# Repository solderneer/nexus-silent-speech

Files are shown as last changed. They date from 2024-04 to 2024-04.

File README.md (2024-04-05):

# Nexus, a session-independent silent speech interface
A novel approach to session-independent silent speech recognition systems with a multiplexed star electrode array, developed for my final year dissertation at University College London (UCL). Includes datasets, code, and electronics CAD files.

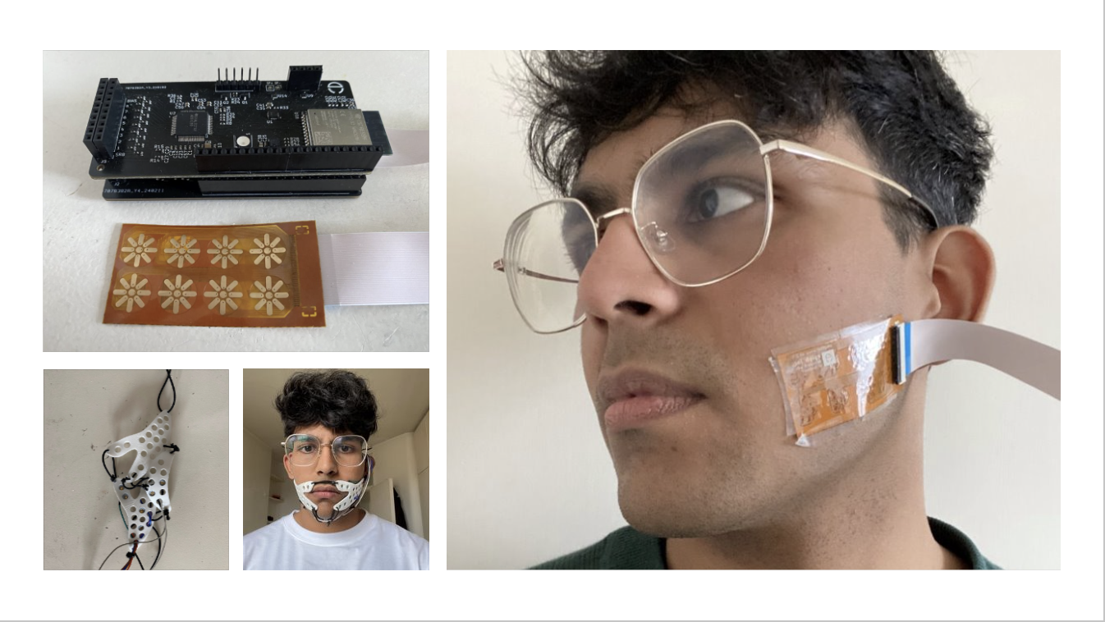
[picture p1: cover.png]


## Overview
This repository houses my final year dissertation project at University College London (UCL), focused on developing a novel multiplexed star electrode array to address the challenges of cross-session variability in silent speech recognition systems. This innovative approach leverages configurable electrode orientations to significantly enhance the signal-to-noise ratio (SNR) of surface electromyography (sEMG) signals, leading to improved recognition accuracy across sessions.

## Project Objectives
- To investigate the impact of cross-session variability on the accuracy of silent speech recognition systems.
- To design, develop, and evaluate a multiplexed star electrode array capable of adjusting electrode orientations for optimal muscle-electrode alignment.
- To compare the performance of the novel star electrode array against traditional electrode configurations in terms of SNR and silent speech recognition accuracy.

## Results Summary
The project successfully demonstrated the potential of the star electrode array to achieve superior muscle-electrode alignment, resulting in a significant increase in SNR compared to control configurations. Most notably, the array displayed a remarkable 41% relative improvement in cross-session classification accuracy, underscoring its effectiveness in mitigating the challenges posed by session-dependent variability.

## Contents
- `datasets/`: Contains the sEMG datasets collected during the project, across multiple sessions and with different electrode configurations.
- `code/`: Includes all code developed for signal acquisition, signal processing, feature extraction, and classification tasks.
- `cad/`: Houses the electronics CAD files for the star electrode array and control circuitry, enabling replication and further research.
- `docs/`: Additional project documentation, including project report and presentation slides.

## Contact
For any inquiries or collaboration proposals, please contact [Shan](https://solderneer.me) at [sudhar393@gmail.com](mailto://sudhar393@gmail.com).

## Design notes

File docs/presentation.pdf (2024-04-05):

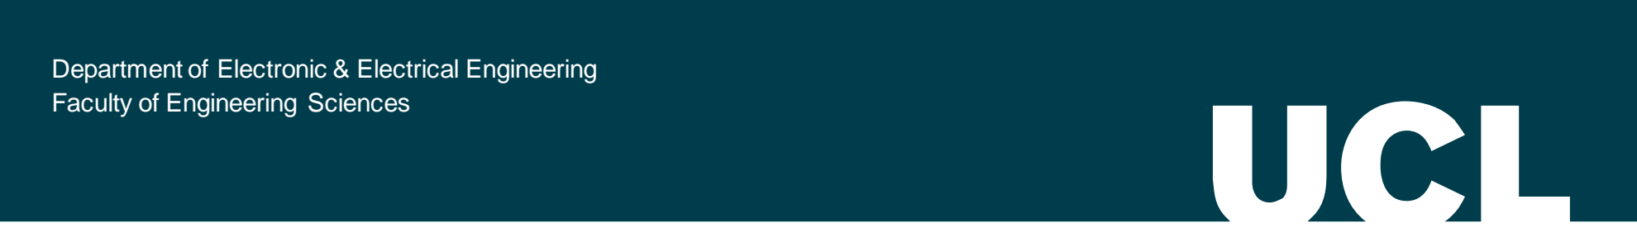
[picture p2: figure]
Faculty of Engineering Sciences

Slide 1 of 7

# A multiplexed star electrode array for session-independent silent speech recognition

# Sudharshan Sundaramahalingam

## Supervisor: Dr Arsam Shiraz

Department of Electronic & Electrical Engineering

### Silent speech recognition

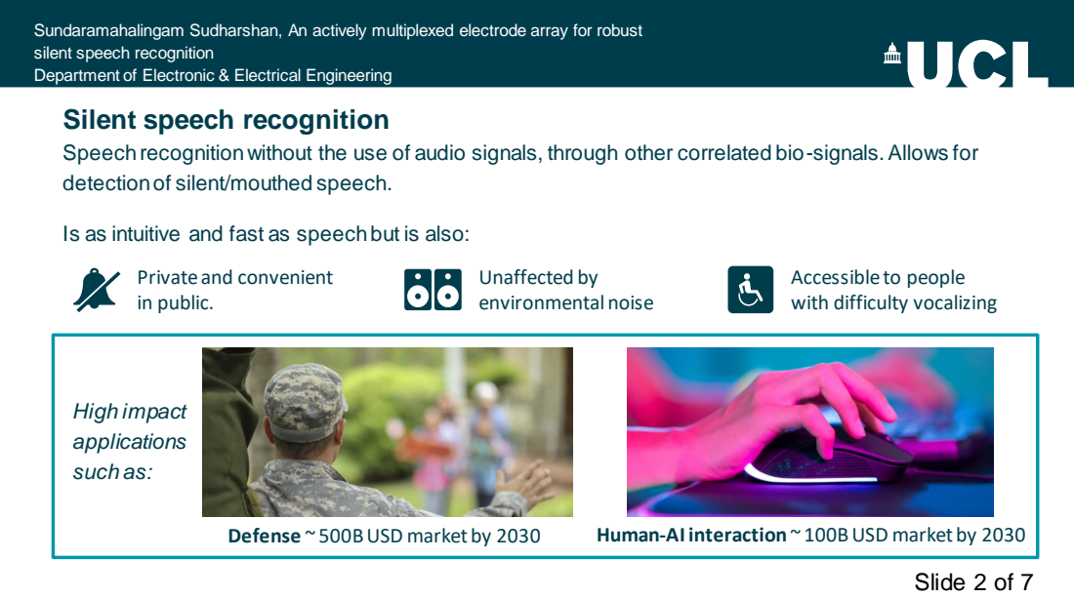
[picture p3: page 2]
Unaffected by environmental noise; High impact; applications; such as:; Defense ~ 500B USD market by 2030; Human-AI interaction ~ 100B USD market by 2030

Sundaramahalingam Sudharshan, An actively multiplexed electrode array for robust
silent speech recognition
Department of Electronic & Electrical Engineering

Speech recognition without the use of audio signals, through other correlated bio-signals. Allows for
detection of silent/mouthed speech.

Is as intuitive and fast as speech but is also:

Private and convenient
in public.

Accessible to people
with difficulty vocalizing

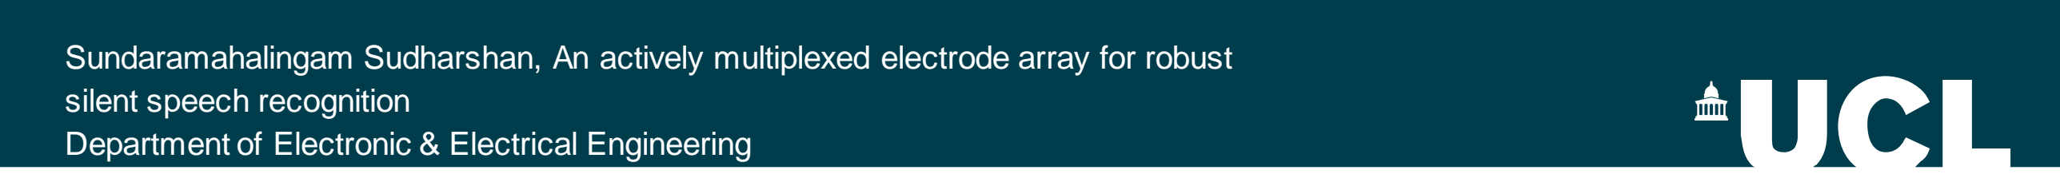
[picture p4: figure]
silent speech recognition

Department of Electronic & Electrical Engineering

### EMG-based silent speech recognition

Electromyography (EMG) signals from facial muscles is a common modality for silent speech recognition.

Electrodes | Signal Acquisition

Digital
Filters

Word
Classifier

Typical Architecture:

System performance requires precise electrode positions, accuracy reduces to 40% after electrode shift.

State of the art
AlterEgo (2019), 91% accuracy over a 30-word vocabulary

Replicated state-of-the-art with a custom electrode brace

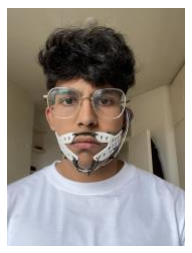
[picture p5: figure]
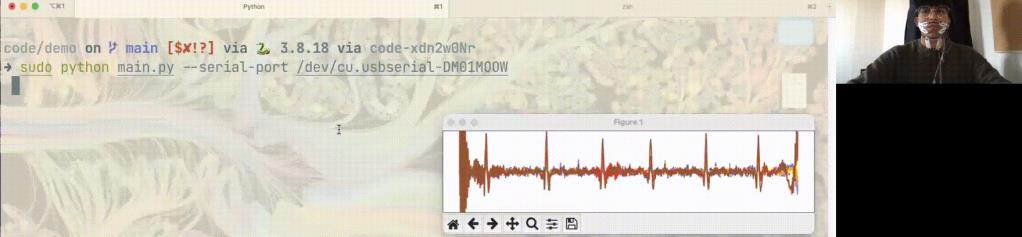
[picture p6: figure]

Research Question:
Investigating the impact of electrode alignment with facial muscles to maximise signal-to-noise ratio (SNR) in silent speech interfaces.

Department of Electronic & Electrical Engineering

### Design and Development

Develop an 8-channel electrode array capable of actively switching the orientation of its electrodes.

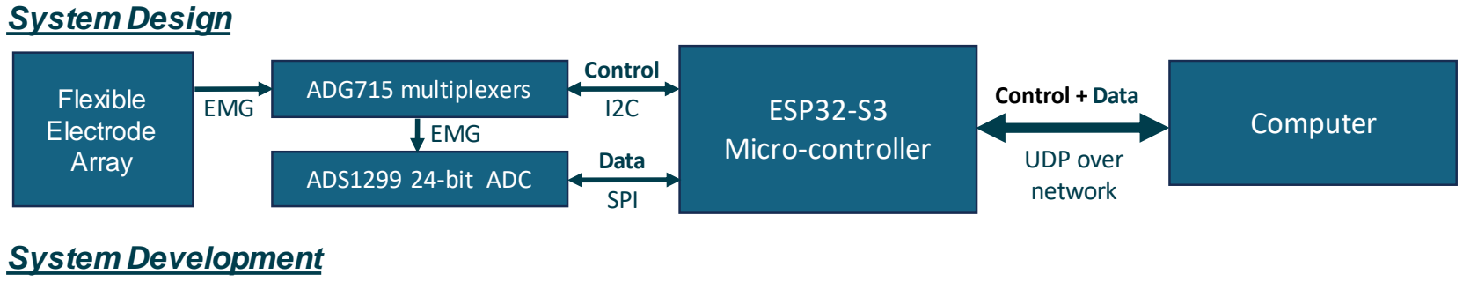
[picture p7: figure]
System Design; Flexible Electrode Array; ADG715 multiplexers; ADS1299 24-bit ADC; ESP32-S3 Micro-controller; Computer EMG EMG; Control I2C; Data SPI; Control + Data; UDP over network; System Development
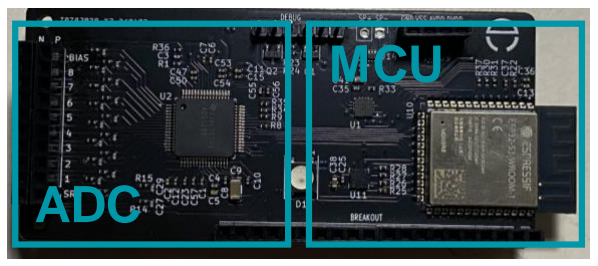
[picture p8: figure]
ADC; MCU
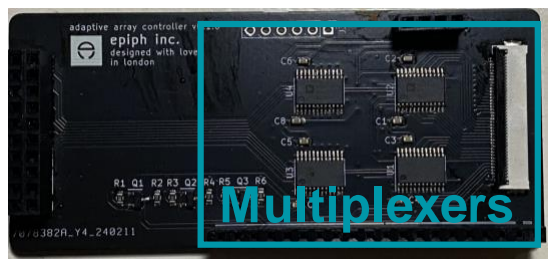
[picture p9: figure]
Multiplexers
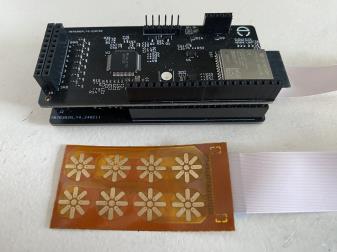
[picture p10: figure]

Main Control Board | Multiplexer Board | Flexible Electrodes (top) multiplexed, (bottom) control

Full Setup

Department of Electronic & Electrical Engineering

### Experimental Procedure and Development

Methodology

1. Record one minute of noise in a relaxed state.
2. Record a phonetically balanced passage that ensures a variety of speech muscle activations are sampled.

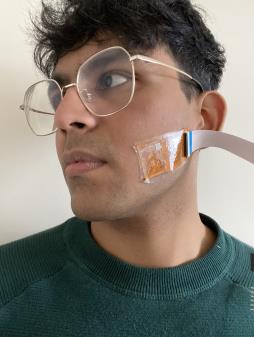
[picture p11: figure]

3. Calculate SNR using mean-squared value of noise and recorded signal.
4. Repeat for each electrode direction (0, 45, 90, 135) + all directions + no directions selected + control array.
5. Repeat across 2 sessions to sample variability in the presence of electrode shift.

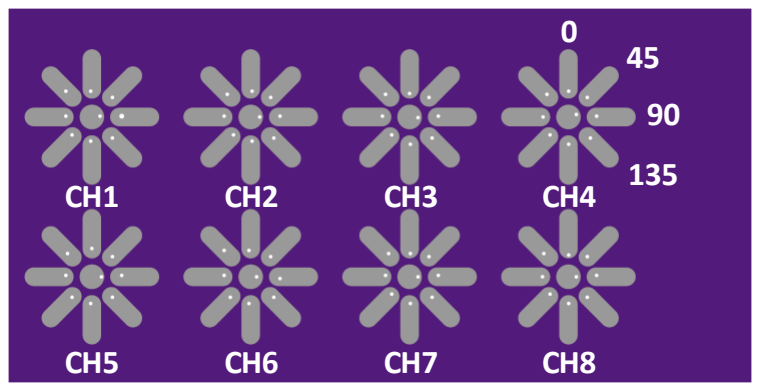
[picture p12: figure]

Detailed view of electrode array: showing electrode directions and channels

User wearing electrodes:
Arrows indicate orientation compared to figure above.

Electrodes adhered with
bio-safe double-sided tape.

Identify electrode directions which maximize SNR, and investigate variability in directions due to electrode shift.

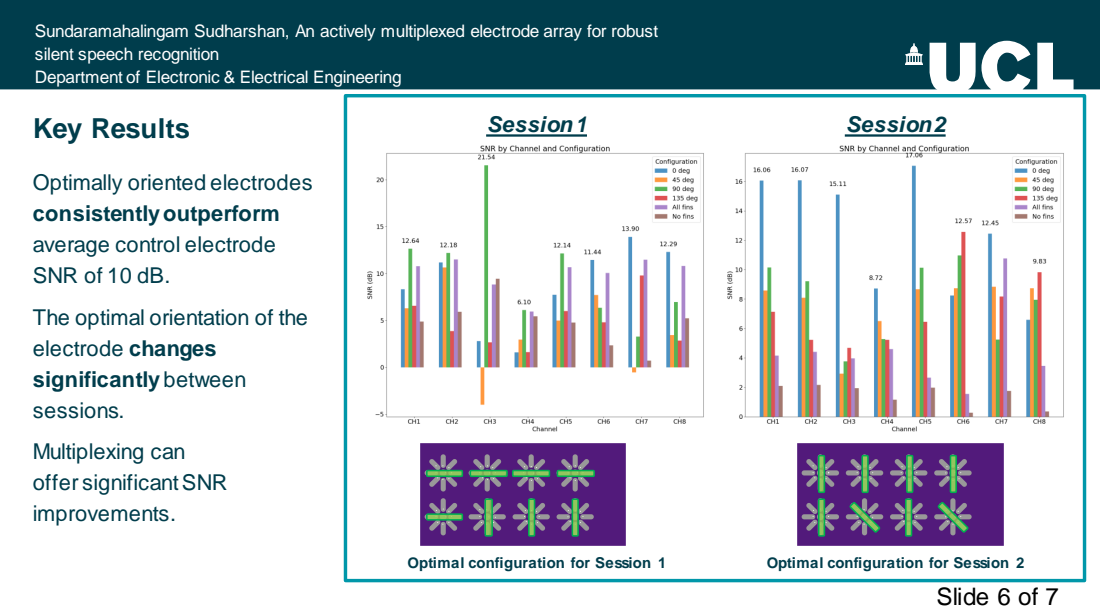
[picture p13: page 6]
Key Results; Session 1; Session 2; Optimal configuration for Session 1; Optimal configuration for Session 2

silent speech recognition
Department of Electronic & Electrical Engineering

Optimally oriented electrodes
consistently outperform
average control electrode
SNR of 10 dB.

The optimal orientation of the
electrode changes
significantly between
sessions.

Multiplexing can
offer significant SNR
improvements.

Department of Electronic & Electrical Engineering

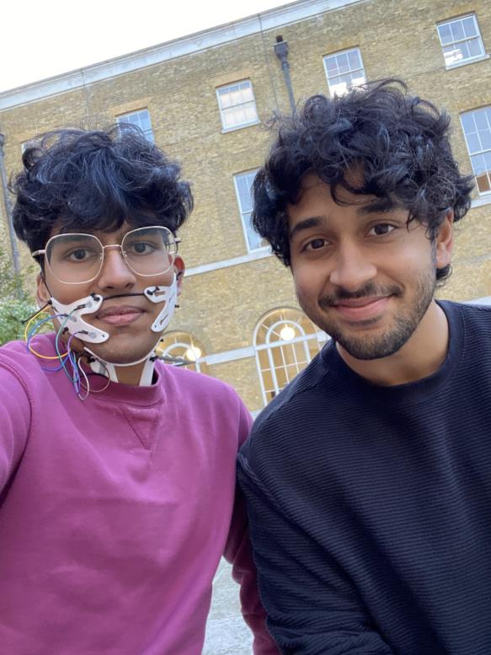
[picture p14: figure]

### Conclusion

1. A novel approach to optimizing SNR for silent speech recognition through electrode alignment is investigated.
2. A multiplexing system enabling configurable electrode orientation is developed.
3. Results show evidence that dynamic electrode alignment has the potential to boost SNR significantly compared to a static electrode array.
4. System can be improved with automatic electrode alignment for user-administrable silent speech interfaces that are robust to electrode placement.

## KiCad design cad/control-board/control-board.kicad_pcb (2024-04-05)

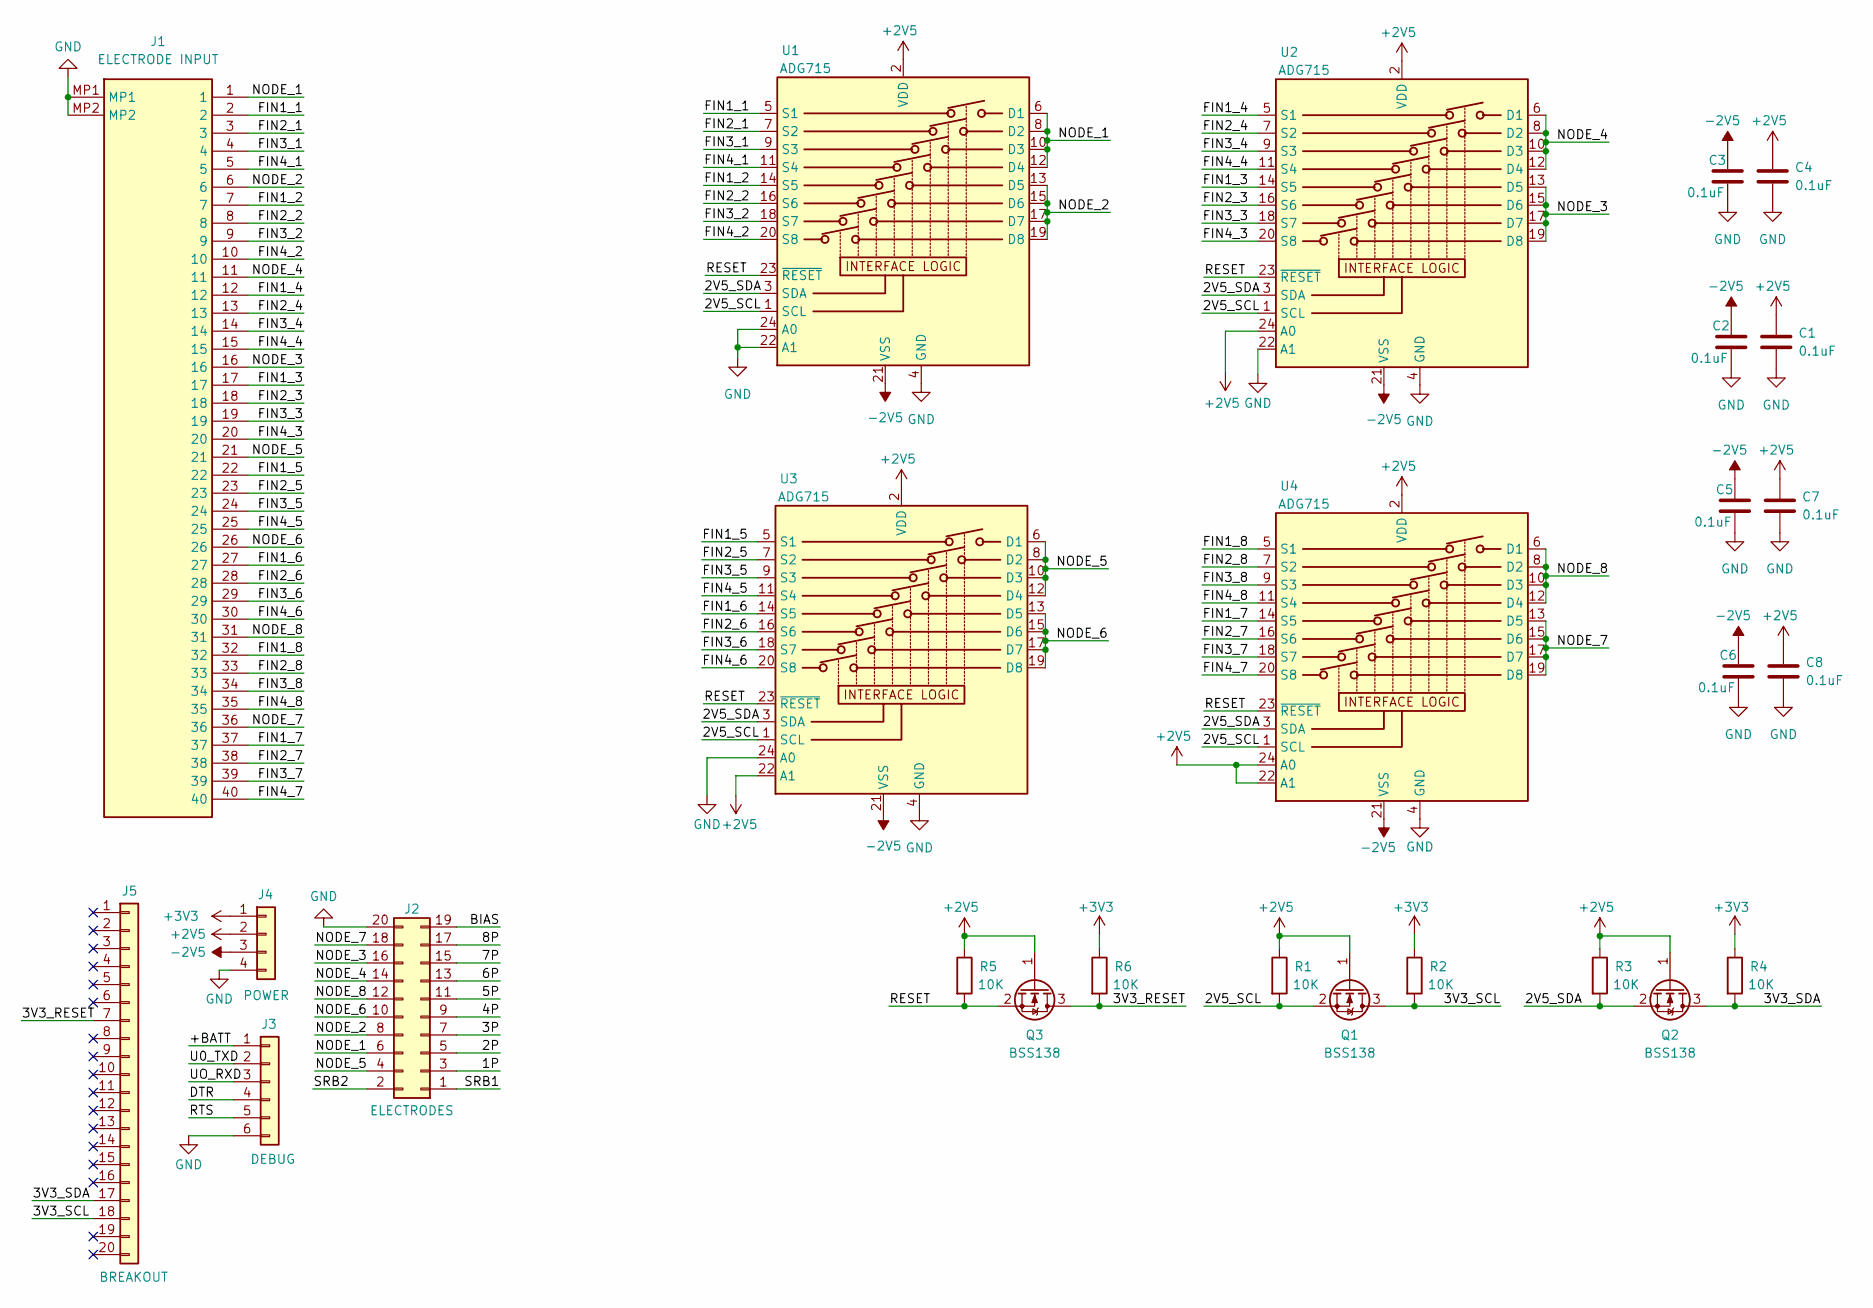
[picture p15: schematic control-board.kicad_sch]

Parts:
C1, C2, C3, C4, C5, C6, C7, C8: 0.1uF; C_0603_1608Metric
J1: ELECTRODE INPUT; F32D1A7Y121040; Manufacturer_Part_Number F32D-1A7Y1-21040
J2: ELECTRODES; PinHeader_2x10_P2.54mm_Vertical
J3: DEBUG; PinHeader_1x06_P2.54mm_Vertical
J4: POWER; PinHeader_1x04_P2.54mm_Vertical
J5: BREAKOUT; PinHeader_1x20_P2.54mm_Vertical
Q1, Q2, Q3: BSS138; SOT-23
R1, R2, R3, R4, R5, R6: 10K; R_0603_1608Metric
U1, U2, U3, U4: ADG715; TSSOP-24_4.4x7.8mm_P0.65mm

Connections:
+2V5: C1.1, C4.1, C7.1, C8.1, J4.2, Q1.1 (G), Q2.1 (G), Q3.1 (G), R1.1, R3.1, R5.1, U1.2 (VDD), U2.2 (VDD), U2.24 (A0), U3.2 (VDD), U3.22 (A1), U4.2 (VDD), U4.22 (A1), U4.24 (A0)
+3V3: J4.1, R2.1, R4.1, R6.1
-2V5: C2.1, C3.1, C5.1, C6.1, J4.3, U1.21 (VSS), U2.21 (VSS), U3.21 (VSS), U4.21 (VSS)
/1P: J2.3
/2P: J2.5
/2V5_SCL: Q1.2 (S), R1.2, U1.1 (SCL), U2.1 (SCL), U3.1 (SCL), U4.1 (SCL)
/2V5_SDA: Q2.2 (S), R3.2, U1.3 (SDA), U2.3 (SDA), U3.3 (SDA), U4.3 (SDA)
/3P: J2.7
/3V3_RESET: J5.7, Q3.3 (D), R6.2
/3V3_SCL: J5.18, Q1.3 (D), R2.2
/3V3_SDA: J5.17, Q2.3 (D), R4.2
/4P: J2.9
/5P: J2.11
/6P: J2.13
/7P: J2.15
/8P: J2.17
/+BATT: J3.1
/BIAS: J2.19
/DTR: J3.4
/FIN1_1: J1.2, U1.5 (S1)
/FIN1_2: J1.7, U1.14 (S5)
/FIN1_3: J1.17, U2.14 (S5)
/FIN1_4: J1.12, U2.5 (S1)
/FIN1_5: J1.22, U3.5 (S1)
/FIN1_6: J1.27, U3.14 (S5)
/FIN1_7: J1.37, U4.14 (S5)
/FIN1_8: J1.32, U4.5 (S1)
/FIN2_1: J1.3, U1.7 (S2)
/FIN2_2: J1.8, U1.16 (S6)
/FIN2_3: J1.18, U2.16 (S6)
/FIN2_4: J1.13, U2.7 (S2)
/FIN2_5: J1.23, U3.7 (S2)
/FIN2_6: J1.28, U3.16 (S6)
/FIN2_7: J1.38, U4.16 (S6)
/FIN2_8: J1.33, U4.7 (S2)
/FIN3_1: J1.4, U1.9 (S3)
/FIN3_2: J1.9, U1.18 (S7)
/FIN3_3: J1.19, U2.18 (S7)
/FIN3_4: J1.14, U2.9 (S3)
/FIN3_5: J1.24, U3.9 (S3)
/FIN3_6: J1.29, U3.18 (S7)
/FIN3_7: J1.39, U4.18 (S7)
/FIN3_8: J1.34, U4.9 (S3)
/FIN4_1: J1.5, U1.11 (S4)
/FIN4_2: J1.10, U1.20 (S8)
/FIN4_3: J1.20, U2.20 (S8)
/FIN4_4: J1.15, U2.11 (S4)
/FIN4_5: J1.25, U3.11 (S4)
/FIN4_6: J1.30, U3.20 (S8)
/FIN4_7: J1.40, U4.20 (S8)
/FIN4_8: J1.35, U4.11 (S4)
/NODE_1: J1.1, J2.6, U1.6 (D1), U1.8 (D2), U1.10 (D3), U1.12 (D4)
/NODE_2: J1.6, J2.8, U1.13 (D5), U1.15 (D6), U1.17 (D7), U1.19 (D8)
/NODE_3: J1.16, J2.16, U2.13 (D5), U2.15 (D6), U2.17 (D7), U2.19 (D8)
/NODE_4: J1.11, J2.14, U2.6 (D1), U2.8 (D2), U2.10 (D3), U2.12 (D4)
/NODE_5: J1.21, J2.4, U3.6 (D1), U3.8 (D2), U3.10 (D3), U3.12 (D4)
/NODE_6: J1.26, J2.10, U3.13 (D5), U3.15 (D6), U3.17 (D7), U3.19 (D8)
/NODE_7: J1.36, J2.18, U4.13 (D5), U4.15 (D6), U4.17 (D7), U4.19 (D8)
/NODE_8: J1.31, J2.12, U4.6 (D1), U4.8 (D2), U4.10 (D3), U4.12 (D4)
/RESET: Q3.2 (S), R5.2, U1.23 (~RESET), U2.23 (~RESET), U3.23 (~RESET), U4.23 (~RESET)
/RTS: J3.5
/SRB1: J2.1
/SRB2: J2.2
/U0_TXD: J3.2
/UO_RXD: J3.3
GND: C1.2, C2.2, C3.2, C4.2, C5.2, C6.2, C7.2, C8.2, J1.MP1, J1.MP2, J2.20, J3.6, J4.4, U1.4 (GND), U1.22 (A1), U1.24 (A0), U2.4 (GND), U2.22 (A1), U3.4 (GND), U3.24 (A0), U4.4 (GND)

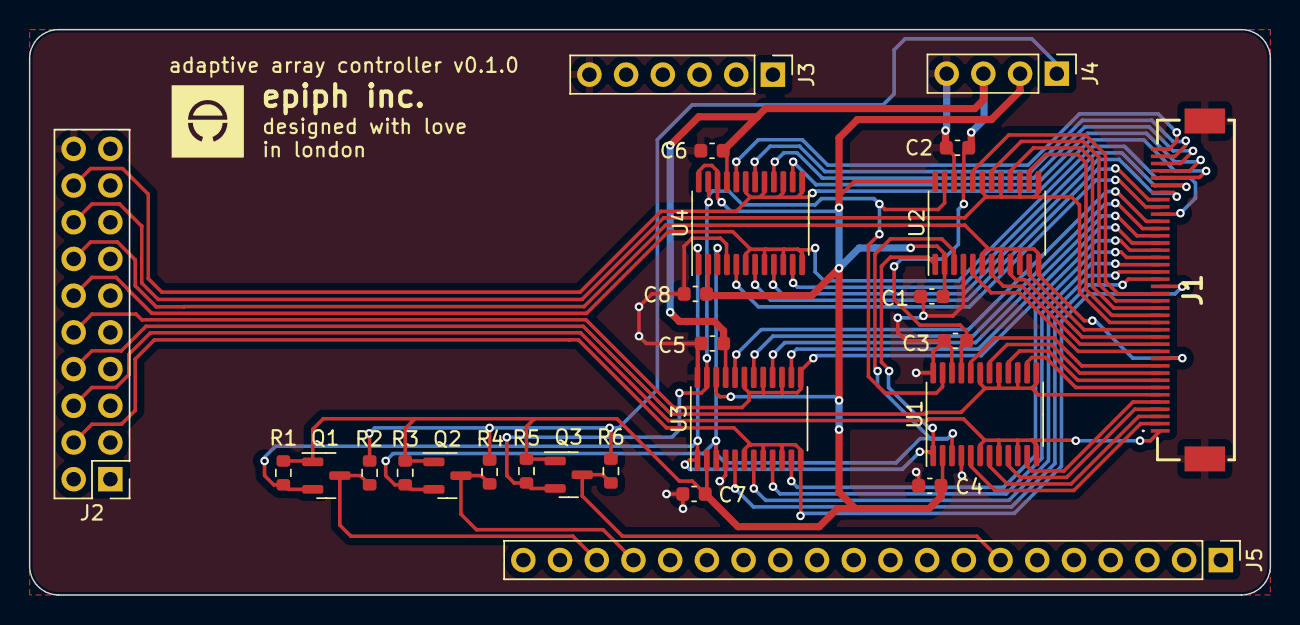
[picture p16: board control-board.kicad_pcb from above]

Board: 2 copper layers, 85.9 x 39.1 mm, 26 parts (0 on the bottom side), 50 nets.

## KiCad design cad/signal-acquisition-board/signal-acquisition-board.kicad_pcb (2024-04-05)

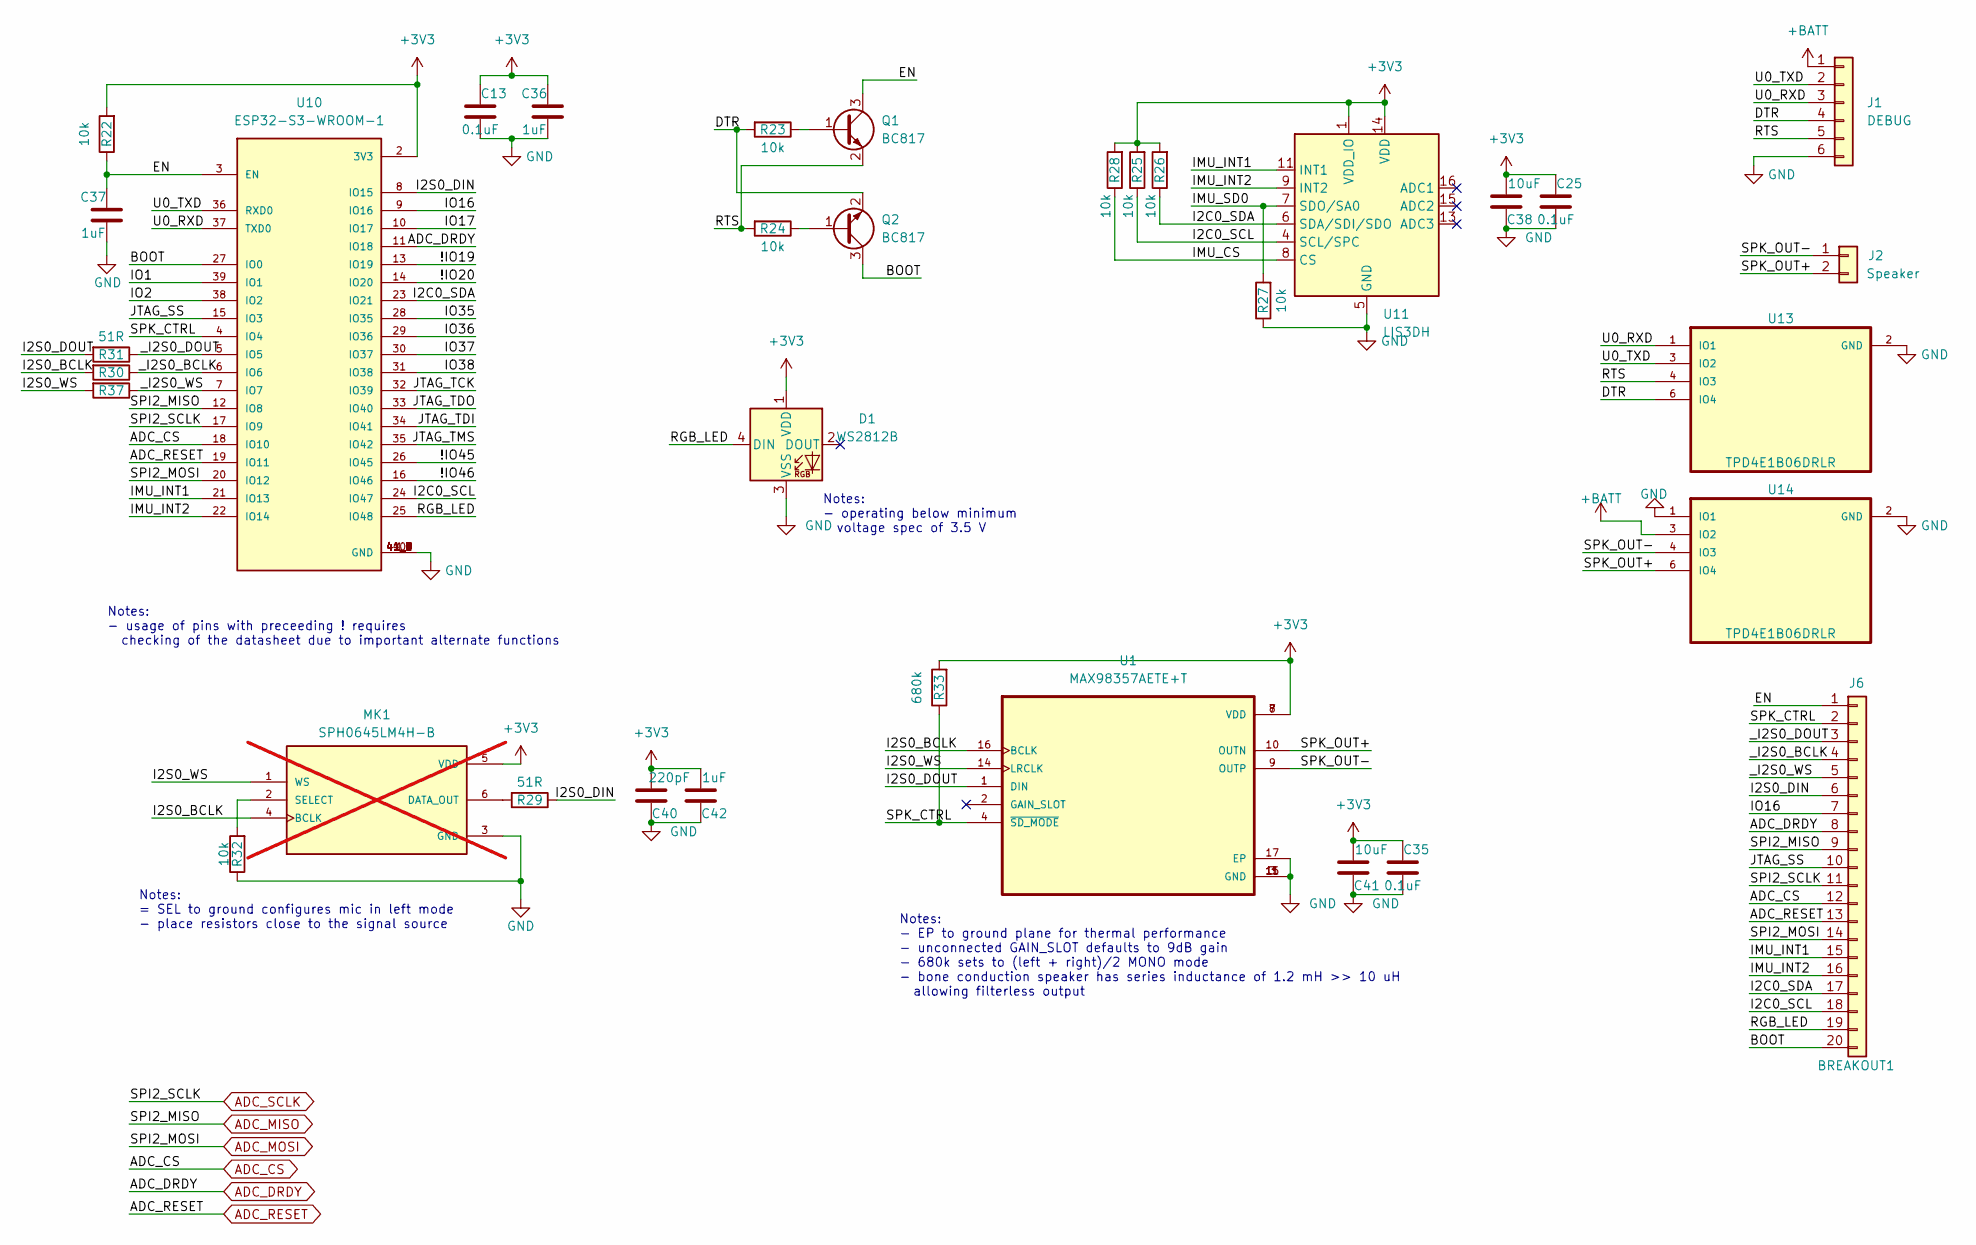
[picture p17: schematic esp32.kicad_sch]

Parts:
C13, C25, C35: 0.1uF; C_0402_1005Metric; Manufacturer Part No. 0402ZD104KAT2A; JLCPCB Part No. C2649532
C36, C37, C42: 1uF; C_0402_1005Metric; Manufacturer Part No. CC0402MRX5R6BB105; JLCPCB Part No. C113791
C38, C41: 10uF; C_0603_1608Metric; Manufacturer Part No. 0603X106M100NT; JLCPCB Part No. C91150
C40: 220pF; C_0402_1005Metric; Manufacturer Part No. C1005X7R221KGT; JLCPCB Part No. C424337
D1: WS2812B; LED_WS2812B_PLCC4_5.0x5.0mm_P3.2mm; Manufacturer Part No. WS2812B-B/T; JLCPCB Part No. C2761795
J1: DEBUG; PinHeader_1x06_P2.54mm_Vertical
J2: Speaker; PinHeader_1x02_P2.54mm_Vertical
J6: BREAKOUT1; PinHeader_1x20_P2.54mm_Vertical
MK1: SPH0645LM4H-B; MIC_SPH0645LM4H-B; Manufacturer Part No. SPH0645LM4H-B-8; JLCPCB Part No. C19190864; not fitted
Q1, Q2: BC817; SOT-23; Manufacturer Part No. BC817; JLCPCB Part No. C475629
R22, R23, R24, R25, R26, R27, R28, R32: 10k; R_0402_1005Metric; Manufacturer Part No. 0402WGF1002TCE; JLCPCB Part No. C25744
R29, R30, R31, R37: 51R; R_0402_1005Metric; Manufacturer Part No. CR-02FL6---51R; JLCPCB Part No. C279983
R33: 680k; R_0402_1005Metric; Manufacturer Part No. RMC10K684FTH; JLCPCB Part No. C323627
U1: MAX98357AETE+T; Manufacturer Part No. MAX98357AETE+T; JLCPCB Part No. C910544
U10: ESP32-S3-WROOM-1; Manufacturer Part No. ESP32-S3-WROOM-1(N8R8); JLCPCB Part No. C2913201
U11: LIS3DH; LGA-16_3x3mm_P0.5mm_LayoutBorder3x5y; Manufacturer Part No. LIS3DHTR; JLCPCB Part No. C15134
U13, U14: TPD4E1B06DRLR; Manufacturer Part No. TPD4E1B06DRLR; JLCPCB Part No. C1972953

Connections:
+3V3: C13.2, C25.2, C35.2, C36.1, C38.1, C40.1, C41.1, C42.1, D1.1 (VDD), MK1.5 (VDD), R22.2, R25.2, R26.2, R28.2, R33.2, U1.7 (VDD), U1.8 (VDD), U10.2 (3V3), U11.1 (VDD_IO), U11.14 (VDD); also elsewhere on the board
+BATT: J1.1, U14.3 (IO2); also elsewhere on the board
/mcu/!IO19: U10.13 (IO19)
/mcu/!IO20: U10.14 (IO20)
/mcu/!IO45: U10.26 (IO45)
/mcu/!IO46: U10.16 (IO46)
/mcu/BOOT: J6.20, Q2.3 (C), U10.27 (IO0)
/mcu/DTR: J1.4, Q2.2 (E), R23.2, U13.6 (IO4)
/mcu/EN: C37.1, J6.1, Q1.3 (C), R22.1, U10.3 (EN)
/mcu/I2C0_SCL: J6.18, R25.1, U10.24 (IO47), U11.4 (SCL/SPC)
/mcu/I2C0_SDA: J6.17, R26.1, U10.23 (IO21), U11.6 (SDA/SDI/SDO)
/mcu/I2S0_BCLK: MK1.4 (BCLK), R30.2, U1.16 (BCLK)
/mcu/I2S0_DIN: J6.6, R29.1, U10.8 (IO15)
/mcu/I2S0_DOUT: R31.2, U1.1 (DIN)
/mcu/I2S0_WS: MK1.1 (WS), R37.2, U1.14 (LRCLK)
/mcu/IMU_CS: R28.1, U11.8 (CS)
/mcu/IMU_INT1: J6.15, U10.21 (IO13), U11.11 (INT1)
/mcu/IMU_INT2: J6.16, U10.22 (IO14), U11.9 (INT2)
/mcu/IMU_SD0: R27.2, U11.7 (SDO/SA0)
/mcu/IO1: U10.39 (IO1)
/mcu/IO2: U10.38 (IO2)
/mcu/IO16: J6.7, U10.9 (IO16)
/mcu/IO17: U10.10 (IO17)
/mcu/IO35: U10.28 (IO35)
/mcu/IO36: U10.29 (IO36)
/mcu/IO37: U10.30 (IO37)
/mcu/IO38: U10.31 (IO38)
/mcu/JTAG_SS: J6.10, U10.15 (IO3)
/mcu/JTAG_TCK: U10.32 (IO39)
/mcu/JTAG_TDI: U10.34 (IO41)
/mcu/JTAG_TDO: U10.33 (IO40)
/mcu/JTAG_TMS: U10.35 (IO42)
/mcu/RGB_LED: D1.4 (DIN), J6.19, U10.25 (IO48)
/mcu/RTS: J1.5, Q1.2 (E), R24.2, U13.4 (IO3)
/mcu/SPK_CTRL: J6.2, R33.1, U1.4 (~SD_MODE), U10.4 (IO4)
/mcu/SPK_OUT+: J2.2, U1.10 (OUTN), U14.6 (IO4)
/mcu/SPK_OUT-: J2.1, U1.9 (OUTP), U14.4 (IO3)
/mcu/U0_RXD: J1.3, U10.37 (TXD0), U13.1 (IO1)
/mcu/U0_TXD: J1.2, U10.36 (RXD0), U13.3 (IO2)
/mcu/_I2S0_BCLK: J6.4, R30.1, U10.6 (IO6)
/mcu/_I2S0_DOUT: J6.3, R31.1, U10.5 (IO5)
/mcu/_I2S0_WS: J6.5, R37.1, U10.7 (IO7)
ADC_CS: J6.12, U10.18 (IO10); also elsewhere on the board
ADC_DRDY: J6.8, U10.11 (IO18); also elsewhere on the board
ADC_MISO: J6.9, U10.12 (IO8); also elsewhere on the board
ADC_MOSI: J6.14, U10.20 (IO12); also elsewhere on the board
ADC_RESET: J6.13, U10.19 (IO11); also elsewhere on the board
ADC_SCLK: J6.11, U10.17 (IO9); also elsewhere on the board
GND: C13.1, C25.1, C35.1, C36.2, C37.2, C38.2, C40.2, C41.2, C42.2, D1.3 (VSS), J1.6, MK1.3 (GND), R27.1, R32.1, U1.3 (GND), U1.11 (GND), U1.15 (GND), U1.17 (EP), U10.1 (GND), U10.40 (GND), U10.41_1 (GND), U10.41_2 (GND), U10.41_3 (GND), U10.41_4 (GND), U10.41_5 (GND), U10.41_6 (GND), U10.41_7 (GND), U10.41_8 (GND), U10.41_9 (GND), U11.5 (GND), U11.10 (GND), U11.12 (GND), U13.2 (GND), U14.1 (IO1), U14.2 (GND); also elsewhere on the board
unnamed: MK1.6 (DATA_OUT), R29.2
unnamed: MK1.2 (SELECT), R32.2
unnamed: Q1.1 (B), R23.1
unnamed: Q2.1 (B), R24.1

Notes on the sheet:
Notes: = SEL to ground configures mic in left mode - place resistors close to the signal source
Notes: - EP to ground plane for thermal performance - unconnected GAIN_SLOT defaults to 9dB gain - 680k sets to (left + right)/2 MONO mode - bone conduction speaker has series inductance of 1.2 mH >> 10 uH allowing filterless output
Notes: - usage of pins with preceeding ! requires checking of the datasheet due to important alternate functions
Notes: - operating below minimum voltage spec of 3.5 V

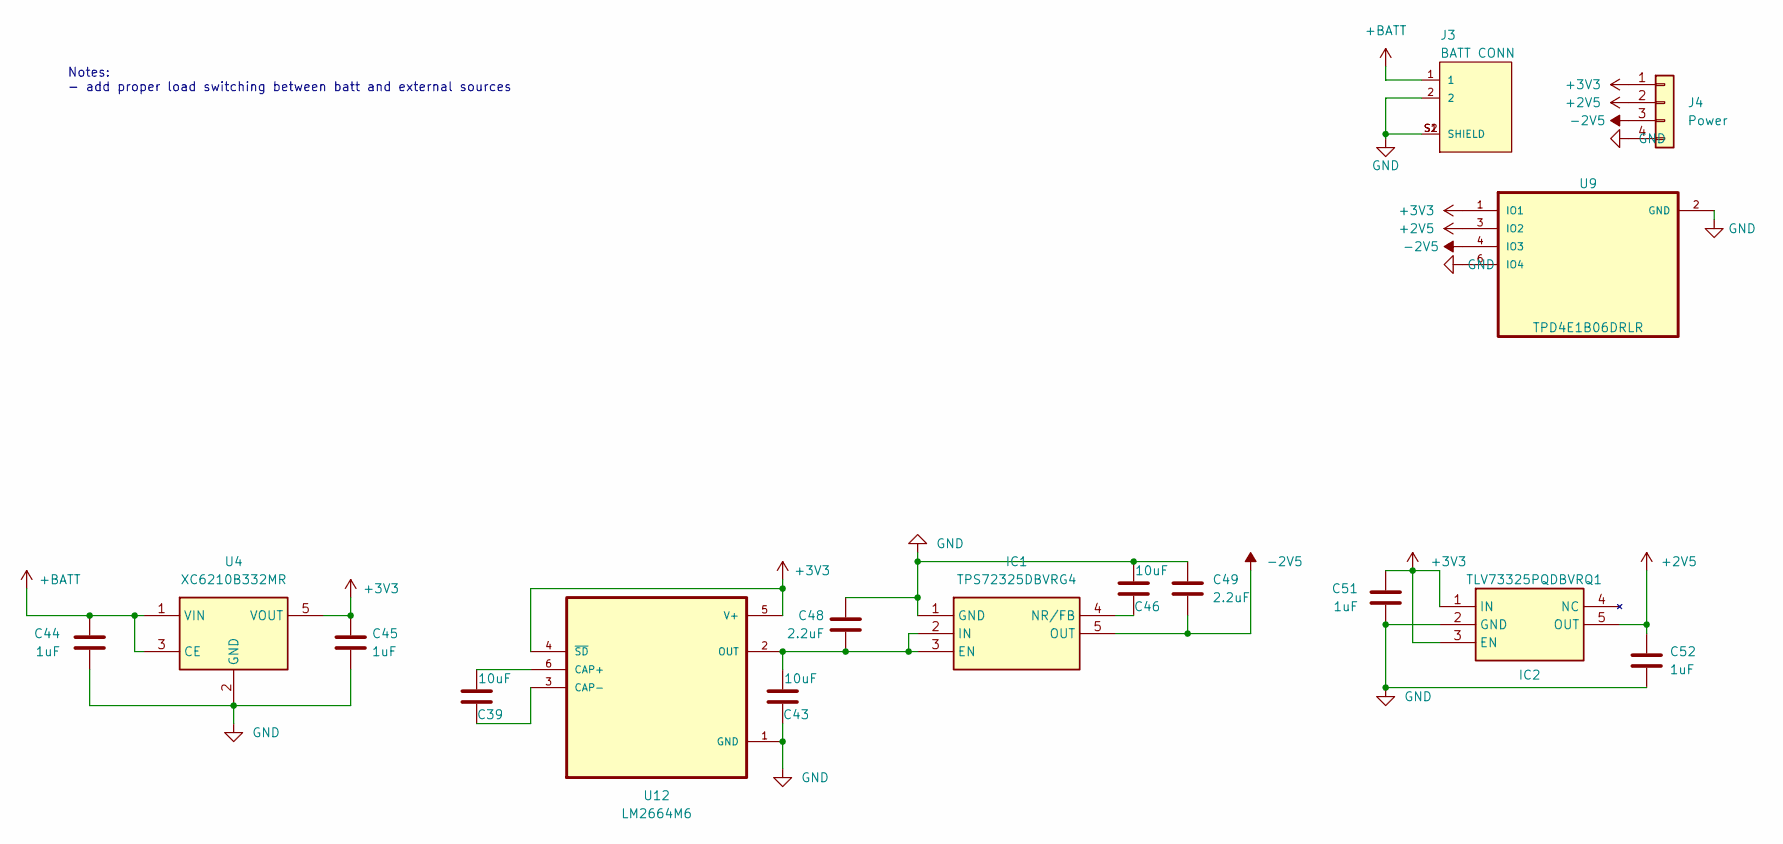
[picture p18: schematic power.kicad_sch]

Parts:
C39, C43, C46: 10uF; C_0603_1608Metric; Manufacturer Part No. 0603X106M100NT; JLCPCB Part No. C91150
C44: 1uF; C_0402_1005Metric; Manufacturer Part No. GRM188R71E105KA12D; JLCPCB Part No. C86020
C45, C51, C52: 1uF; C_0402_1005Metric; Manufacturer Part No. CC0402MRX5R6BB105; JLCPCB Part No. C113791
C48, C49: 2.2uF; C_0402_1005Metric; Manufacturer Part No. GRM155Z71A225KE44D; JLCPCB Part No. C2999759
IC1: TPS72325DBVRG4; Manufacturer Part No. TPS72325DBVRG4; JLCPCB Part No. C3746858
IC2: TLV73325PQDBVRQ1; Manufacturer Part No. TLV73325PQDBVRQ1; JLCPCB Part No. C2860807
J3: BATT CONN; JST_S2B-PH-SM4-TB_LF__SN_; Manufacturer Part No. S2B-PH-SM4-TB(LF)(SN); JLCPCB Part No. C295747
J4: Power; PinHeader_1x04_P2.54mm_Vertical
U4: XC6210B332MR; SOT-23-5; Manufacturer Part No. XC6210B332MR; JLCPCB Part No. C3021084
U9: TPD4E1B06DRLR; Manufacturer Part No. TPD4E1B06DRLR; JLCPCB Part No. C1972953
U12: LM2664M6; Manufacturer Part No. LM2664M6/NOPB; JLCPCB Part No. C840095

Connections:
+2V5: C52.1, IC2.5 (OUT), J4.2, U9.3 (IO2); also elsewhere on the board
+3V3: C45.1, C51.1, IC2.1 (IN), IC2.3 (EN), J4.1, U4.5 (VOUT), U9.1 (IO1), U12.4 (~SD), U12.5 (V+); also elsewhere on the board
+BATT: C44.1, J3.1, U4.1 (VIN), U4.3 (CE); also elsewhere on the board
-2V5: C49.2, IC1.5 (OUT), J4.3, U9.4 (IO3); also elsewhere on the board
GND: C43.2, C44.2, C45.2, C46.1, C48.1, C49.1, C51.2, C52.2, IC1.1 (GND), IC2.2 (GND), J3.2, J3.S1 (SHIELD), J3.S2 (SHIELD), J4.4, U4.2 (GND), U9.2 (GND), U9.6 (IO4), U12.1 (GND); also elsewhere on the board
unnamed: C43.1, C48.2, IC1.2 (IN), IC1.3 (EN), U12.2 (OUT)
unnamed: C46.2, IC1.4 (NR/FB)
unnamed: C39.1, U12.6 (CAP+)
unnamed: C39.2, U12.3 (CAP-)

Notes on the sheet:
Notes: - add proper load switching between batt and external sources

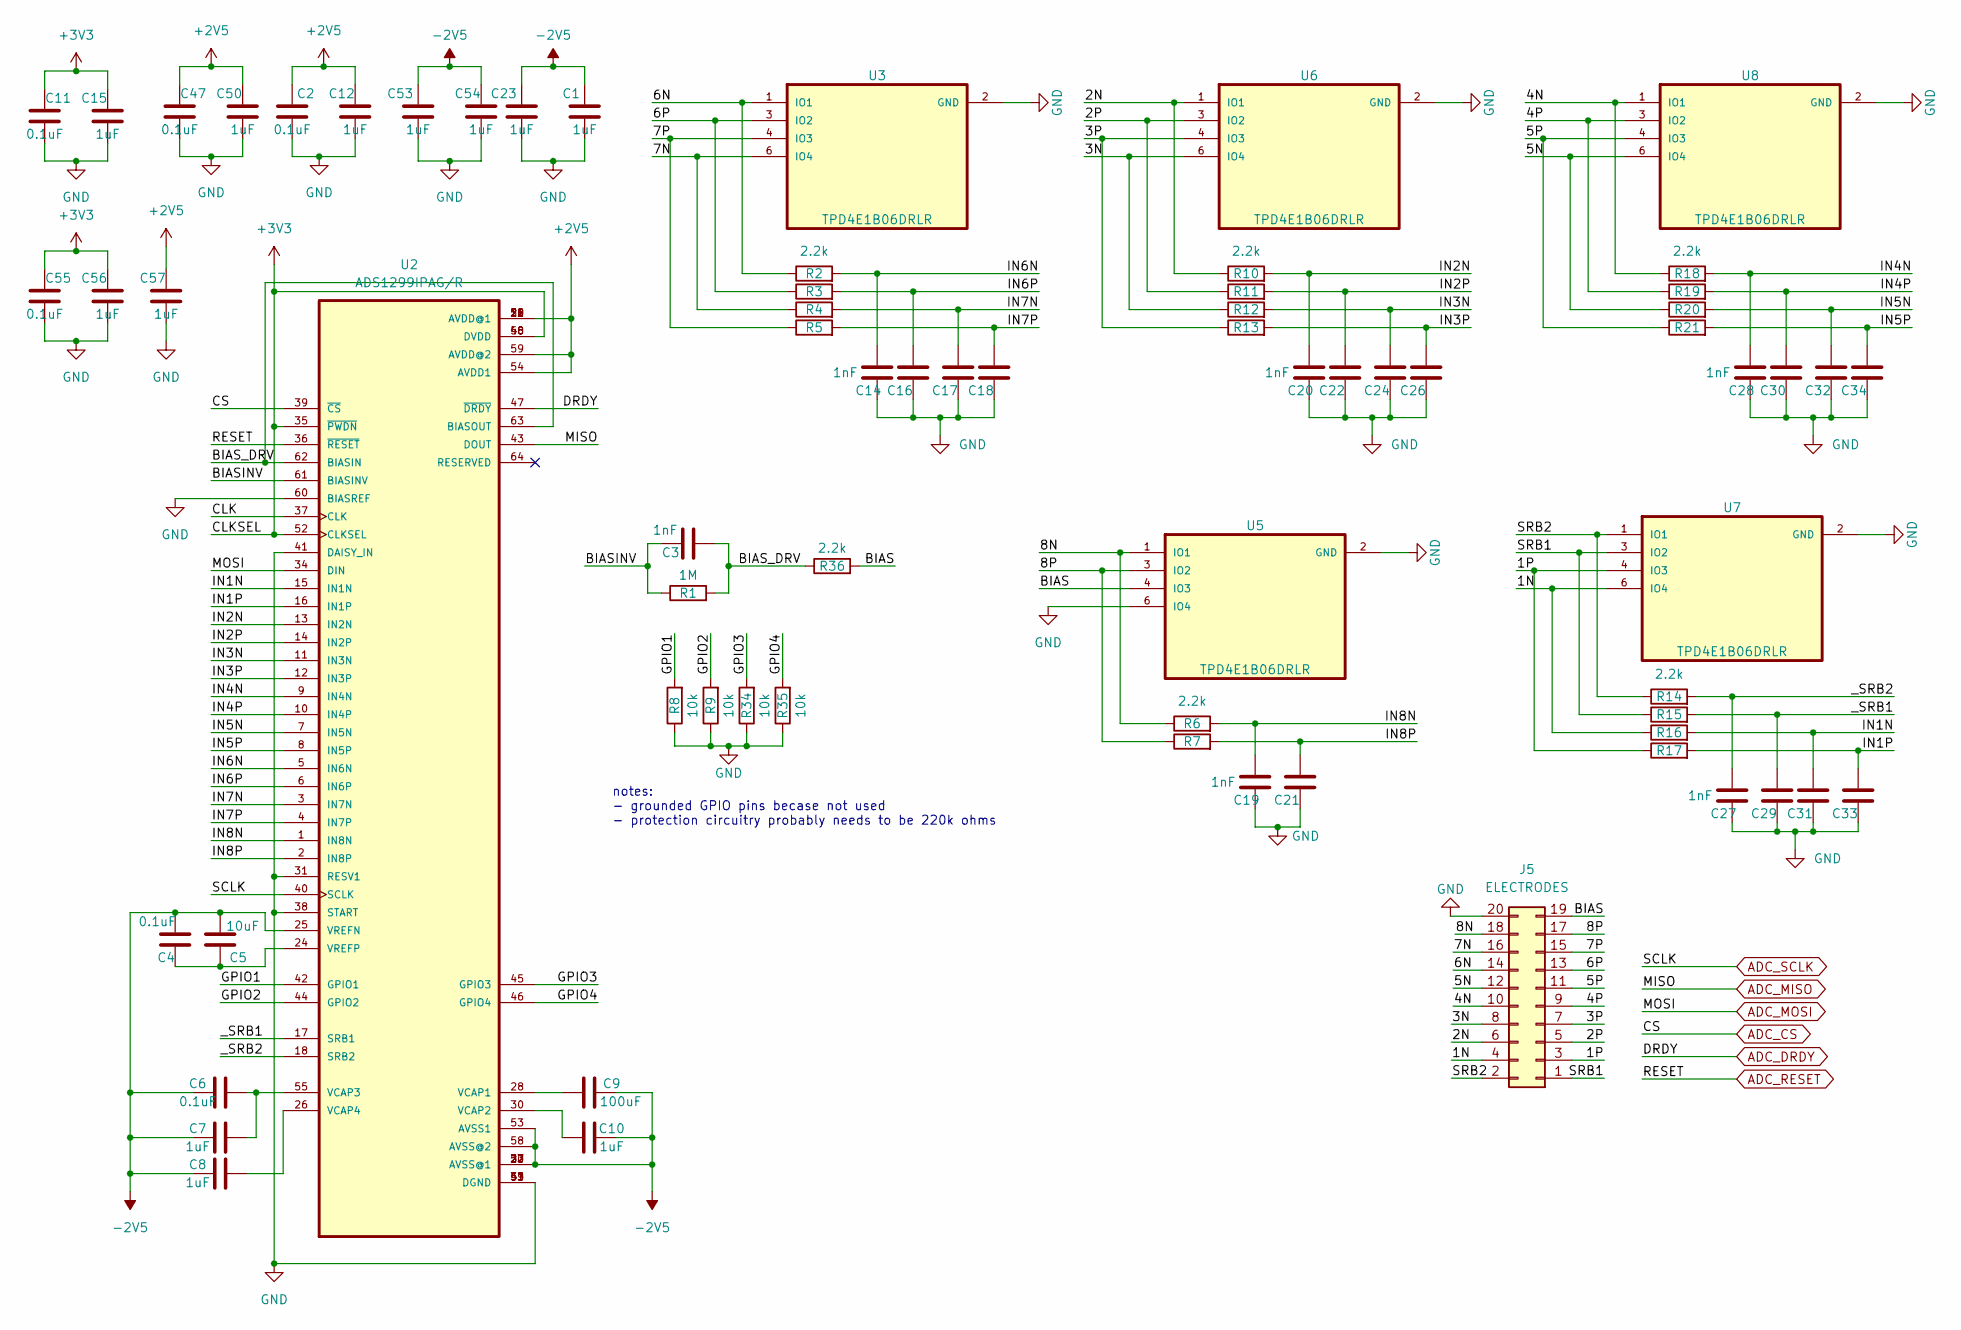
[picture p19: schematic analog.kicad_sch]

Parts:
C1, C7, C8, C10, C12, C15, C23, C50, C53, C54, C56, C57: 1uF; C_0402_1005Metric; Manufacturer Part No. CC0402MRX5R6BB105; JLCPCB Part No. C113791
C2, C4, C6, C11, C47, C55: 0.1uF; C_0402_1005Metric; Manufacturer Part No. 0402ZD104KAT2A; JLCPCB Part No. C2649532
C3, C14, C16, C17, C18, C19, C20, C21, C22, C24, C26, C27, C28, C29, C30, C31, C32, C33, C34: 1nF; C_0402_1005Metric; Manufacturer Part No. GCM1555C1H102FA16D; JLCPCB Part No. C126493
C5: 10uF; C_0402_1005Metric; Manufacturer Part No. GRM155C80J106ME11D; JLCPCB Part No. C237279
C9: 100uF; C_1206_3216Metric; Manufacturer Part No. CL31A107MPKNNWE; JLCPCB Part No. C7588440
J5: ELECTRODES; PinHeader_2x10_P2.54mm_Vertical
R1: 1M; R_0402_1005Metric; Manufacturer Part No. CR-02FL6----1M; JLCPCB Part No. C409676
R2, R3, R4, R5, R6, R7, R10, R11, R12, R13, R14, R15, R16, R17, R18, R19, R20, R21, R36: 2.2k; R_0402_1005Metric; Manufacturer Part No. RMC04022.2K1%N; JLCPCB Part No. C325418
R8, R9, R34, R35: 10k; R_0402_1005Metric; Manufacturer Part No. 0402WGF1002TCE; JLCPCB Part No. C25744
U2: ADS1299IPAG/R; ADS1299IPAG; Manufacturer Part No. ADS1299IPAGR; JLCPCB Part No. C476817
U3, U5, U6, U7, U8: TPD4E1B06DRLR; Manufacturer Part No. TPD4E1B06DRLR; JLCPCB Part No. C1972953

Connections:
+2V5: C2.1, C12.1, C47.1, C50.1, C57.1, U2.19 (AVDD@1), U2.21 (AVDD@1), U2.22 (AVDD@1), U2.54 (AVDD1), U2.56 (AVDD@1), U2.59 (AVDD@2); also elsewhere on the board
+3V3: C11.1, C15.1, C55.1, C56.1, U2.35 (~PWDN), U2.48 (DVDD), U2.50 (DVDD), U2.52 (CLKSEL); also elsewhere on the board
-2V5: C1.1, C4.1, C5.1, C6.1, C7.1, C8.1, C9.2, C10.2, C23.1, C53.1, C54.1, U2.20 (AVSS@1), U2.23 (AVSS@1), U2.25 (VREFN), U2.32 (AVSS@1), U2.53 (AVSS1), U2.57 (AVSS@1), U2.58 (AVSS@2); also elsewhere on the board
/analog/1N: J5.4, R16.1, U7.6 (IO4)
/analog/1P: J5.3, R17.1, U7.4 (IO3)
/analog/2N: J5.6, R10.1, U6.1 (IO1)
/analog/2P: J5.5, R11.1, U6.3 (IO2)
/analog/3N: J5.8, R12.1, U6.6 (IO4)
/analog/3P: J5.7, R13.1, U6.4 (IO3)
/analog/4N: J5.10, R18.1, U8.1 (IO1)
/analog/4P: J5.9, R19.1, U8.3 (IO2)
/analog/5N: J5.12, R20.1, U8.6 (IO4)
/analog/5P: J5.11, R21.1, U8.4 (IO3)
/analog/6N: J5.14, R2.1, U3.1 (IO1)
/analog/6P: J5.13, R3.1, U3.3 (IO2)
/analog/7N: J5.16, R4.1, U3.6 (IO4)
/analog/7P: J5.15, R5.1, U3.4 (IO3)
/analog/8N: J5.18, R6.1, U5.1 (IO1)
/analog/8P: J5.17, R7.1, U5.3 (IO2)
/analog/BIAS: J5.19, R36.2, U5.4 (IO3)
/analog/BIASINV: C3.2, R1.1, U2.61 (BIASINV)
/analog/BIAS_DRV: C3.1, R1.2, R36.1, U2.62 (BIASIN), U2.63 (BIASOUT)
/analog/CLK: U2.37 (CLK)
/analog/GPIO1: R8.2, U2.42 (GPIO1)
/analog/GPIO2: R9.2, U2.44 (GPIO2)
/analog/GPIO3: R34.2, U2.45 (GPIO3)
/analog/GPIO4: R35.2, U2.46 (GPIO4)
/analog/IN1N: C31.1, R16.2, U2.15 (IN1N)
/analog/IN1P: C33.1, R17.2, U2.16 (IN1P)
/analog/IN2N: C20.1, R10.2, U2.13 (IN2N)
/analog/IN2P: C22.1, R11.2, U2.14 (IN2P)
/analog/IN3N: C24.1, R12.2, U2.11 (IN3N)
/analog/IN3P: C26.1, R13.2, U2.12 (IN3P)
/analog/IN4N: C28.1, R18.2, U2.9 (IN4N)
/analog/IN4P: C30.1, R19.2, U2.10 (IN4P)
/analog/IN5N: C32.1, R20.2, U2.7 (IN5N)
/analog/IN5P: C34.1, R21.2, U2.8 (IN5P)
/analog/IN6N: C14.1, R2.2, U2.5 (IN6N)
/analog/IN6P: C16.1, R3.2, U2.6 (IN6P)
/analog/IN7N: C17.1, R4.2, U2.3 (IN7N)
/analog/IN7P: C18.1, R5.2, U2.4 (IN7P)
/analog/IN8N: C19.1, R6.2, U2.1 (IN8N)
/analog/IN8P: C21.1, R7.2, U2.2 (IN8P)
/analog/SRB1: J5.1, R15.1, U7.3 (IO2)
/analog/SRB2: J5.2, R14.1, U7.1 (IO1)
/analog/_SRB1: C29.1, R15.2, U2.17 (SRB1)
/analog/_SRB2: C27.1, R14.2, U2.18 (SRB2)
ADC_CS: U2.39 (~CS); also elsewhere on the board
ADC_DRDY: U2.47 (~DRDY); also elsewhere on the board
ADC_MISO: U2.43 (DOUT); also elsewhere on the board
ADC_MOSI: U2.34 (DIN); also elsewhere on the board
ADC_RESET: U2.36 (~RESET); also elsewhere on the board
ADC_SCLK: U2.40 (SCLK); also elsewhere on the board
GND: C1.2, C2.2, C11.2, C12.2, C14.2, C15.2, C16.2, C17.2, C18.2, C19.2, C20.2, C21.2, C22.2, C23.2, C24.2, C26.2, C27.2, C28.2, C29.2, C30.2, C31.2, C32.2, C33.2, C34.2, C47.2, C50.2, C53.2, C54.2, C55.2, C56.2, C57.2, J5.20, R8.1, R9.1, R34.1, R35.1, U2.31 (RESV1), U2.33 (DGND), U2.38 (START), U2.41 (DAISY_IN), U2.49 (DGND), U2.51 (DGND), U2.60 (BIASREF), U3.2 (GND), U5.2 (GND), U5.6 (IO4), U6.2 (GND), U7.2 (GND), U8.2 (GND); also elsewhere on the board
unnamed: C9.1, U2.28 (VCAP1)
unnamed: C10.1, U2.30 (VCAP2)
unnamed: C6.2, C7.2, U2.55 (VCAP3)
unnamed: C8.2, U2.26 (VCAP4)
unnamed: C4.2, C5.2, U2.24 (VREFP)

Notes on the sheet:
notes: - grounded GPIO pins becase not used - protection circuitry probably needs to be 220k ohms

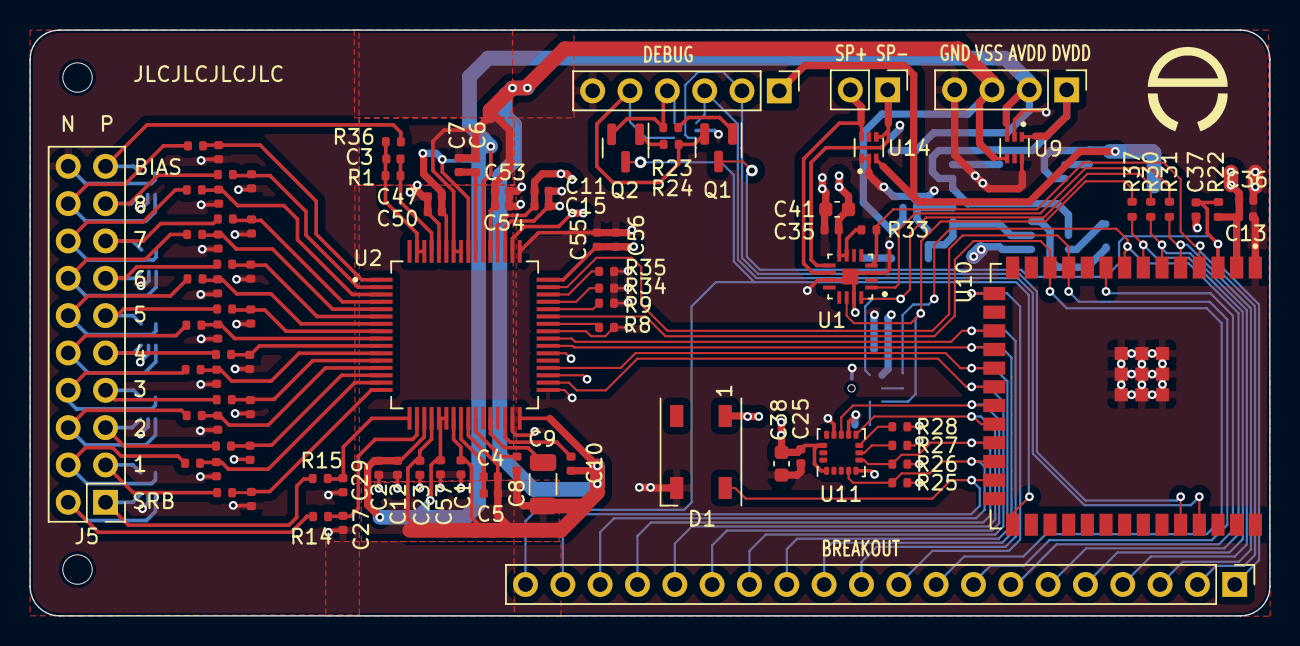
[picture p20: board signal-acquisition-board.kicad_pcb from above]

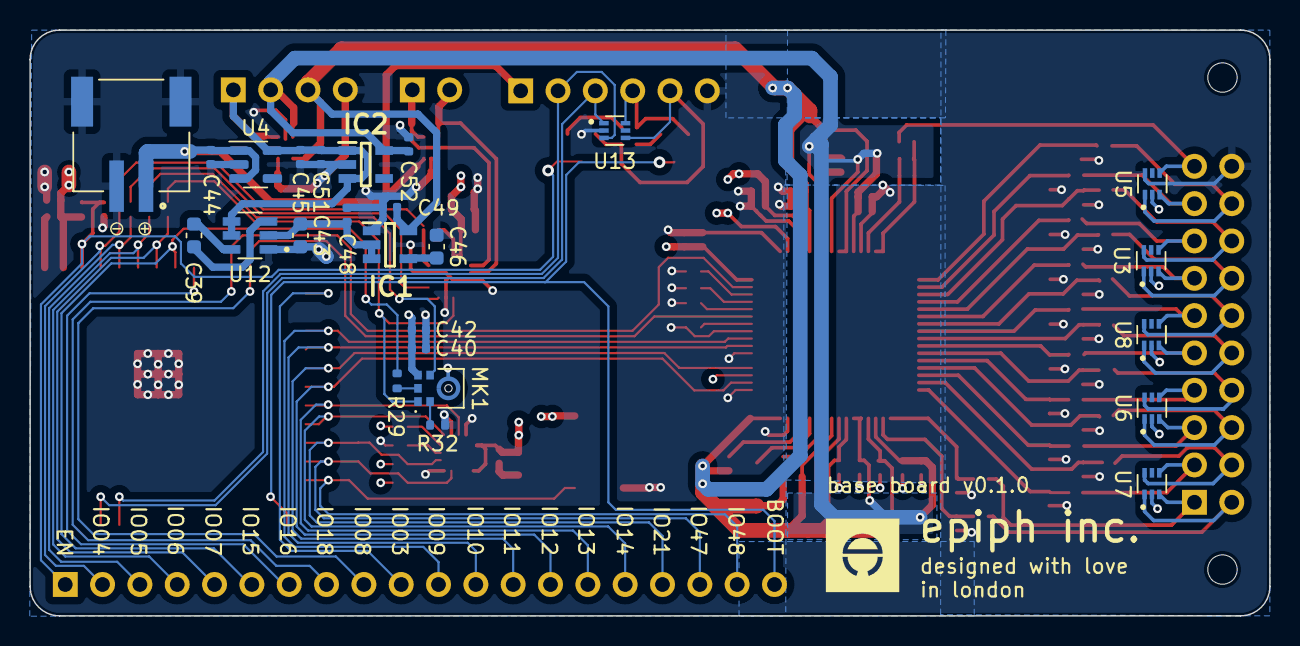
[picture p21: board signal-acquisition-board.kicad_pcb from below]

Board: 4 copper layers, 84.4 x 39.9 mm, 120 parts (25 on the bottom side), 92 nets.

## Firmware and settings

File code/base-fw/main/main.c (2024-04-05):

#include <stdio.h>
#include <sys/socket.h>
#include <time.h>
#include <sys/time.h>

// ESP includes
#include "esp_log.h"
#include "esp_err.h"
#include "esp_wifi.h"
#include "esp_system.h"
#include "esp_event.h"
#include "nvs_flash.h"
#include "esp_task_wdt.h"
#include "esp_sntp.h"
#include "driver/i2c_master.h"

// FreeRTOS includes
#include "freertos/FreeRTOS.h"
#include "freertos/event_groups.h"
#include "freertos/task.h"

// Custom components
#include "ads1299_interface.h"
#include "adg715_interface.h"
#include "status_interface.h"

// #define BASE_WIFI_SSID "BT-RSC2QS"
// #define BASE_WIFI_PASS "tVDHXba7t9GeK4"

#define BASE_WIFI_SSID "Shan's Room"
#define BASE_WIFI_PASS "iamironman"

#define BASE_WIFI_MAXIMUM_RETRY 5

static const char *TAG = "base-board-fw";

/******** WIFI CONFIG **********/
/* FreeRTOS event group to signal when we are connected*/
static EventGroupHandle_t s_wifi_event_group;

/* The event group allows multiple bits for each event, but we only care about two events:
 * - we are connected to the AP with an IP
 * - we failed to connect after the maximum amount of retries */
#define WIFI_CONNECTED_BIT BIT0
#define WIFI_FAIL_BIT BIT1

// Retry number for WiFi connection
static int s_retry_num = 0;

/********* TCP/IP CONFIG ********/
#define HOST_IP_ADDR "192.168.1.143"
#define HOST_IP_PORT 8080

int sock = -1;
int addr_family = 0;
int ip_protocol = 0;

/********* ADS1299 INTERFACE PINS *******/

#define ADS1299_SPI_HOST             SPI2_HOST
#define ADS1299_SPI_CLOCK_SPEED_HZ   (2*1000*1000)
#define ADS1299_MISO_PIN             GPIO_NUM_8
#define ADS1299_MOSI_PIN             GPIO_NUM_12
#define ADS1299_SCLK_PIN             GPIO_NUM_9
#define ADS1299_CS_PIN               GPIO_NUM_10
#define ADS1299_DRDY_PIN             GPIO_NUM_18
#define ADS1299_RESET_PIN            GPIO_NUM_11

/********* MASTER I2C and ADG715 **********/

#define BOARD_I2C_PORT -1
#define BOARD_I2C_SDA_PIN GPIO_NUM_21
#define BOARD_I2C_SCL_PIN GPIO_NUM_47
#define ADG715_RESET_PIN GPIO_NUM_16

const uint8_t adg715_addr[4] = {0x48, 0x49, 0x4A, 0x4B};

/********* STATUS LED CONFIG *********/

#define STATUS_LED_GPIO GPIO_NUM_48

/********* COMM BUFFER ***********/

#define BUFFER_SIZE (256 * 16) // TODO: Optimize this
#define BUFFER_FLUSH_SIZE (256 * 15)
static char buffer[BUFFER_SIZE];
static int buffer_index = 0;

// System state machine
enum base_state_t
{
    WIFI_DISCONNECTED,
    WIFI_CONNECTING,
    SERVER_CONNECTING,
    STREAMING
};
static enum base_state_t base_state = WIFI_CONNECTING;

void time_sync_notification_cb(struct timeval *tv)
{
    ESP_LOGI(TAG, "Notification of a time synchronization event");
}

static void event_handler(void *arg, esp_event_base_t event_base,
                          int32_t event_id, void *event_data)
{
    if (event_base == WIFI_EVENT && event_id == WIFI_EVENT_STA_START)
    {
        esp_wifi_connect();
    }
    else if (event_base == WIFI_EVENT && event_id == WIFI_EVENT_STA_DISCONNECTED)
    {
        if (s_retry_num < BASE_WIFI_MAXIMUM_RETRY)
        {
            esp_wifi_connect();
            s_retry_num++;
            ESP_LOGI(TAG, "retry to connect to the AP");
        }
        else
        {
            xEventGroupSetBits(s_wifi_event_group, WIFI_FAIL_BIT);
        }
        ESP_LOGI(TAG, "connect to the AP fail");
    }
    else if (event_base == IP_EVENT && event_id == IP_EVENT_STA_GOT_IP)
    {
        ip_event_got_ip_t *event = (ip_event_got_ip_t *)event_data;
        ESP_LOGI(TAG, "got ip:" IPSTR, IP2STR(&event->ip_info.ip));
        s_retry_num = 0;
        xEventGroupSetBits(s_wifi_event_group, WIFI_CONNECTED_BIT);
    }
}

void wifi_init_sta(void)
{
    s_wifi_event_group = xEventGroupCreate();

    ESP_ERROR_CHECK(esp_netif_init());

    ESP_ERROR_CHECK(esp_event_loop_create_default());
    esp_netif_create_default_wifi_sta();

    wifi_init_config_t cfg = WIFI_INIT_CONFIG_DEFAULT();
    ESP_ERROR_CHECK(esp_wifi_init(&cfg));

    esp_event_handler_instance_t instance_any_id;
    esp_event_handler_instance_t instance_got_ip;
    ESP_ERROR_CHECK(esp_event_handler_instance_register(WIFI_EVENT,
                                                        ESP_EVENT_ANY_ID,
                                                        &event_handler,
                                                        NULL,
                                                        &instance_any_id));
    ESP_ERROR_CHECK(esp_event_handler_instance_register(IP_EVENT,
                                                        IP_EVENT_STA_GOT_IP,
                                                        &event_handler,
                                                        NULL,
                                                        &instance_got_ip));

    wifi_config_t wifi_config = {
        .sta = {
            .ssid = BASE_WIFI_SSID,
            .password = BASE_WIFI_PASS,
            .threshold.authmode = WIFI_AUTH_WPA2_PSK},
    };
    ESP_ERROR_CHECK(esp_wifi_set_mode(WIFI_MODE_STA));
    ESP_ERROR_CHECK(esp_wifi_set_config(WIFI_IF_STA, &wifi_config));
    ESP_ERROR_CHECK(esp_wifi_start());

    ESP_LOGI(TAG, "wifi_init_sta finished.");
}

void app_main(void)
{
    /********* SETUP CODE **********/

    // Setup NVS Flash
    esp_err_t ret = nvs_flash_init();
    if (ret == ESP_ERR_NVS_NO_FREE_PAGES || ret == ESP_ERR_NVS_NEW_VERSION_FOUND)
    {
        ESP_ERROR_CHECK(nvs_flash_erase());
        ret = nvs_flash_init();
    }
    ESP_ERROR_CHECK(ret);   

    // Setup time
    time_t now;
    struct tm timeinfo;
    time(&now);
    localtime_r(&now, &timeinfo);

    // Setup status
    status_config_t status_config = {
        .led_pin = STATUS_LED_GPIO
    };
    status_handle_t* status_handle;
    status_init(&status_config, &status_handle);
    status_red(status_handle);

    // Setup I2C master bus
    ESP_LOGI(TAG, "Initializing I2C Bus...");
    i2c_master_bus_config_t i2c_master_config = {
        .clk_source = I2C_CLK_SRC_DEFAULT,
        .i2c_port = BOARD_I2C_PORT,
        .sda_io_num = BOARD_I2C_SDA_PIN,
        .scl_io_num = BOARD_I2C_SCL_PIN,
        .glitch_ignore_cnt = 7,
        .flags.enable_internal_pullup = false
    };

    i2c_master_bus_handle_t i2c_bus_handle;
    ESP_ERROR_CHECK(i2c_new_master_bus(&i2c_master_config, &i2c_bus_handle));

    /* Setup 4 ADG715s */
    adg715_handle_t* adg715_handle[4];
    for(int i = 0; i < sizeof(adg715_addr); i++) {
        adg715_config_t adg715_config = {
            .i2c_bus = i2c_bus_handle,
            .i2c_addr = adg715_addr[i],
            .reset_pin = ADG715_RESET_PIN
        };
        adg715_init(&adg715_config, &adg715_handle[i]);
        adg715_set(adg715_handle[i],0x00);
    }

    //adg715_set(adg715_handle[0], 0x81); // U1 (MSB S8, LSB S1) (CH3, CH2)
    //adg715_set(adg715_handle[1], 0x28); // U2 (CH7, CH6)
    //adg715_set(adg715_handle[2], 0x88); // U3 (CH4, CH1)
    //adg715_set(adg715_handle[3], 0x88); // U4 (CH8, CH5)

    // Setup SPI2 master bus
    ESP_LOGI(TAG, "Initializing SPI%d bus...", ADS1299_SPI_HOST + 1);
    spi_bus_config_t buscfg = {
        .miso_io_num = ADS1299_MISO_PIN,
        .mosi_io_num = ADS1299_MOSI_PIN,
        .sclk_io_num = ADS1299_SCLK_PIN,
        .quadwp_io_num = -1,
        .quadhd_io_num = -1,
        .max_transfer_sz = 32,
    };

    ESP_ERROR_CHECK(spi_bus_initialize(ADS1299_SPI_HOST, &buscfg, SPI_DMA_DISABLED));

    // Setup ADS1299
    ads1299_config_t ads1299_config = {
        .spi_host = ADS1299_SPI_HOST,
        .spi_clock_speed_hz = ADS1299_SPI_CLOCK_SPEED_HZ,
        .miso_pin = ADS1299_MISO_PIN,
        .mosi_pin = ADS1299_MOSI_PIN,
        .sclk_pin = ADS1299_SCLK_PIN,
        .cs_pin = ADS1299_CS_PIN,
        .drdy_pin = ADS1299_DRDY_PIN,
        .reset_pin = ADS1299_RESET_PIN
    };

    ads1299_handle_t* ads1299_handle;
    ads1299_init(&ads1299_config, &ads1299_handle);
    ads1299_set_datarate(ads1299_handle, DR_250SPS);
    
    //ads1299_set_ch_all(ads1299_handle, false);
    //ads1299_set_ch(ads1299_handle, 1, true);
    //ads1299_set_srb2_ch(ads1299_handle, 1, true);
    //ads1299_set_bias_ch(ads1299_handle, 1, BIAS_N, true);
    //ads1299_set_bias_ch(ads1299_handle, 1, BIAS_P, true);

    ads1299_data_rate_t dr = 0;
    ads1299_get_datarate(ads1299_handle, &dr);
    ESP_LOGI(TAG, "Data rate: %d", dr);

    // print all channels state
    for(int i = 0; i < 8; i++) {
        uint8_t reg;

        // ads1299_set_ch_input(ads1299_handle, i, TESTSIG);
        ads1299_set_srb2_ch(ads1299_handle, i, true);
        ads1299_set_bias_ch(ads1299_handle, i, BIAS_N, true);

        ads1299_get_ch(ads1299_handle, i, &reg);
        ESP_LOGI(TAG, "CH%d Setting: %x", i, reg);
    }
    
    // TODO: Move this into the ADS1299 component library to be gain dependent
    const double LSB = 2.5 / 24 / (16777216 - 1); // LSB = VREF / Gain / (2^24 - 1)

    /********* STATE MACHINE *******/
    while (1)
    {
        switch (base_state)
        {
        case WIFI_DISCONNECTED:
            // ESP_LOGI(TAG, "Disconnected from Wifi");
            status_red(status_handle);
            break;
        case WIFI_CONNECTING:
            ESP_LOGI(TAG, "Connecting to Wifi");
            status_red(status_handle);

            wifi_init_sta();

            /* Waiting until either the connection is established (WIFI_CONNECTED_BIT) or connection 
             * failed for the maximum number of re-tries (WIFI_FAIL_BIT). The bits are set by 
             * event_handler() (see above) */
            EventBits_t bits = xEventGroupWaitBits(s_wifi_event_group,
                WIFI_CONNECTED_BIT | WIFI_FAIL_BIT, pdFALSE, pdFALSE, portMAX_DELAY);

            if (bits & WIFI_CONNECTED_BIT)
                base_state = SERVER_CONNECTING;
            else if (bits & WIFI_FAIL_BIT)
                base_state = WIFI_DISCONNECTED;
            else
            {
                ESP_LOGE(TAG, "UNEXPECTED EVENT");
                base_state = WIFI_DISCONNECTED;
            }
            break;
        case SERVER_CONNECTING:
            ESP_LOGI(TAG, "[SERVER_DISCONNECTED] Connected to ap SSID:%s password:%s", 
                BASE_WIFI_SSID, BASE_WIFI_PASS);
            ESP_LOGI(TAG, "[SERVER_DISCONNECTED] Looking for server.");
            status_yellow(status_handle);

            // Setup time
            ESP_LOGI(TAG, "[SERVER_DISCONNECTED] Initializing SNTP");
            esp_sntp_setoperatingmode(SNTP_OPMODE_POLL);
            esp_sntp_setservername(0, "pool.ntp.org");
            esp_sntp_set_time_sync_notification_cb(time_sync_notification_cb);
            esp_sntp_init();

            // wait for time to be set
            int retry = 0;
            const int retry_count = 10;
            while (sntp_get_sync_status() == SNTP_SYNC_STATUS_RESET && ++retry < retry_count) {
                ESP_LOGI(TAG, "Waiting for system time to be set... (%d/%d)", retry, retry_count);
                vTaskDelay(2000 / portTICK_PERIOD_MS);
            }
            
            // Setting up UDP socket
            struct sockaddr_in dest_addr;
            dest_addr.sin_addr.s_addr = inet_addr(HOST_IP_ADDR);
            dest_addr.sin_family = AF_INET;
            dest_addr.sin_port = htons(HOST_IP_PORT);
            addr_family = AF_INET;
            ip_protocol = IPPROTO_IP;

            sock = socket(addr_family, SOCK_DGRAM, ip_protocol);
            if (sock < 0) {
                ESP_LOGE(TAG, "Unable to create socket: errno %d", errno);
                vTaskDelay(1000 / portTICK_PERIOD_MS);
                break;
            }

            // Set timeout
            struct timeval timeout;
            timeout.tv_sec = 10;
            timeout.tv_usec = 0;
            setsockopt (sock, SOL_SOCKET, SO_RCVTIMEO, &timeout, sizeof timeout);

            ESP_LOGI(TAG, "Socket created, sending to %s:%d", HOST_IP_ADDR, HOST_IP_PORT);
            base_state = STREAMING;
            break;
        case STREAMING:
            ESP_LOGI(TAG, "[STREAMING] Streaming data.");
            status_green(status_handle);
            ads1299_acquire_bus(ads1299_handle);

            while (1) {
                if (ads1299_ready(ads1299_handle)) {
                    uint32_t status;
                    int32_t res[8];
                    double res_V[8];

                    ads1299_read(ads1299_handle, &status, res);
                    time(&now);

                    // Convert to uV
                    for(int i = 0; i < 8; i++) {
                        res_V[i] = res[i] * LSB;
                    }
                    
                    char temp_buffer[256] = {0};
                    sprintf(temp_buffer, "%lld,%lf,%lf,%lf,%lf,%lf,%lf,%lf,%lf\n", now, res_V[0], res_V[1], res_V[2], res_V[3], res_V[4], res_V[5], res_V[6], res_V[7]);
                    memcpy(&buffer[buffer_index], temp_buffer, 256);
        
                    if (buffer_index + 256 <= BUFFER_FLUSH_SIZE) {
                        buffer_index += 256;
                    } else {
                        // Flush to network
                        int err = sendto(sock, buffer, buffer_index, 0, (struct sockaddr *)&dest_addr, sizeof(dest_addr));
                        buffer_index = 0;

                        if (err < 0) {
                            ESP_LOGE(TAG, "Connection lost: errno %d", errno);
                            break;
                        }               
                    }
                } else {
                    // Reset watchdog
                }
            }

            // Error with UDP, go back to SERVER_CONNECTING
            shutdown(sock, 0);
            close(sock);
            ads1299_release_bus(ads1299_handle);
            base_state = SERVER_CONNECTING;
            break;
        }
    }
}

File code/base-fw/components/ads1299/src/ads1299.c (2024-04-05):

#include "esp_log.h"
#include "driver/gpio.h"
#include "driver/spi_master.h"

#include "ads1299.h"
#include "ads1299_interface.h"

static const char *TAG = "esp_ads1299";

esp_err_t ads1299_init(const ads1299_config_t* config, ads1299_handle_t** out_handle)
{
    esp_err_t err = ESP_OK;

    ads1299_handle_t* handle = (ads1299_handle_t*)malloc(sizeof(ads1299_handle_t));
    if (!handle) {
        ESP_LOGE(TAG, "Failed to allocate memory for ADS1299 device");
        return ESP_ERR_NO_MEM;
    }
    
    // copy config into handle
    *handle = (ads1299_handle_t) {
        .config = *config,
    };

    // Setup DRDY pin
    gpio_config_t gpio_conf = {
        .pin_bit_mask = (1ULL << config->drdy_pin),
        .mode = GPIO_MODE_INPUT,
        .pull_up_en = GPIO_PULLUP_DISABLE,
        .pull_down_en = GPIO_PULLDOWN_DISABLE,
        .intr_type = GPIO_INTR_DISABLE
    };
    gpio_config(&gpio_conf);

    // Setup reset pin
    gpio_conf.pin_bit_mask = (1ULL << config->reset_pin);
    gpio_conf.mode = GPIO_MODE_OUTPUT;
    gpio_conf.pull_up_en = GPIO_PULLUP_ENABLE;
    gpio_config(&gpio_conf);

    // Hold reset high
    gpio_set_level(config->reset_pin, 1);

    // Setup SPI bus
    spi_device_interface_config_t spi_cfg = {
        .command_bits = 8, // Standard commands are 1 byte, except for RREG and WREG
        .address_bits = 0, // Not using this
        .dummy_bits = 0, // Not using this, either
        .mode = 1, // SPI mode 1
        .clock_speed_hz = config->spi_clock_speed_hz,
        .spics_io_num = config->cs_pin,
        .cs_ena_posttrans = 5, // Always hold CS high for 4 t_clk cycles after communication
        .queue_size = 2,
        .input_delay_ns = 0, // TODO: update this for faster, better timing performance
        .flags = 0
    };

    // Attach ads1299 to spi bus
    err = spi_bus_add_device(config->spi_host, &spi_cfg, &(handle->spi));
    if (err == ESP_OK) {
        // Success!

        // Initialization steps
        ads1299_reset(handle);
        ads1299_sdatac(handle);
        _ads1299_rreg(handle, ADS_ID, &(handle->id));
        ESP_LOGI(TAG, "ADS1299 ID: %d", handle->id);
        _ads1299_wreg(handle, ADS_CONFIG2, 0xD5);
        _ads1299_wreg(handle, ADS_CONFIG3, 0xFC);
        // _ads1299_wreg(handle, ADS_MISC1, 0x20);

        int ch = 0;
        for (ch = 0; ch < 8; ch++)
            _ads1299_wreg(handle, ADS_CH1SET + ch, 0x60); // configure to default 24x gain and normal input

        ads1299_start(handle);
        ads1299_rdatac(handle);

        *out_handle = handle;
        return ESP_OK;
    } else {
        ESP_LOGE(TAG, "Failed to initialize SPI device");
        ads1299_deinit(handle); // Release resources
        return err;
    }
}

esp_err_t ads1299_deinit(ads1299_handle_t* handle)
{
    esp_err_t err = ESP_OK;

    // Deregister gpio pin
    gpio_reset_pin(handle->config.drdy_pin);

    if (handle->spi) {
        err = spi_bus_remove_device(handle->spi);
        handle->spi = NULL;
    }

    free(handle); // Release the allocated heap memory
    return err;
}

int ads1299_ready(ads1299_handle_t* handle)
{
    return !gpio_get_level(handle->config.drdy_pin);
}

esp_err_t ads1299_read(ads1299_handle_t* handle, uint32_t* status, int32_t res[])
{
    const uint8_t data_len = 8;

    uint8_t transmit_buf[27] = {0x00};
    uint8_t receive_buf[27] = {0x00};

    spi_transaction_ext_t t = {
        .base = (spi_transaction_t) {
            .flags = SPI_TRANS_VARIABLE_CMD,
            .length = (27 * 8),
            .tx_buffer = transmit_buf,
            .rx_buffer = receive_buf
        },
        .command_bits = 0
    };

    esp_err_t err = spi_device_transmit(handle->spi, &t);

    if (err != ESP_OK) return err;

    // Parse the received data
    for (int i = 0; i < data_len; i++) {
        // Off by 4 because first three is status
        // Sign conversion from 24 bit to 32 bit
        res[i] = (int32_t) (((receive_buf[i*3+3] & 0x80) ? (0xFF) : (0x00)) << 24 |
                ((receive_buf[i*3+3] & 0xFF) << 16) |
                ((receive_buf[i*3+4] & 0xFF) << 8)  |
                ((receive_buf[i*3+5] & 0xFF) << 0));
    }

    *status = (receive_buf[0] << 16) | (receive_buf[1] << 8) | receive_buf[2];
    return ESP_OK;
}

esp_err_t ads1299_acquire_bus(ads1299_handle_t* handle)
{
    return spi_device_acquire_bus(handle->spi, portMAX_DELAY);
}

esp_err_t ads1299_release_bus(ads1299_handle_t* handle)
{
    spi_device_release_bus(handle->spi);
    return ESP_OK;
}

esp_err_t ads1299_cmd(ads1299_handle_t* handle, uint8_t cmd)
{
    spi_transaction_t t = {
        .cmd = cmd,
        .length = 0,
    };

    esp_err_t err = spi_device_transmit(handle->spi, &t);
    if (err != ESP_OK) {
        return err;
    }

    return ESP_OK;
}

esp_err_t ads1299_wakeup(ads1299_handle_t* handle) { return ads1299_cmd(handle, ADS_WAKEUP); }
esp_err_t ads1299_standby(ads1299_handle_t* handle) { return ads1299_cmd(handle, ADS_STANDBY); }
esp_err_t ads1299_start(ads1299_handle_t* handle) { return ads1299_cmd(handle, ADS_START); }
esp_err_t ads1299_stop(ads1299_handle_t* handle) { return ads1299_cmd(handle, ADS_STOP); }
esp_err_t ads1299_rdatac(ads1299_handle_t* handle) { return ads1299_cmd(handle, ADS_RDATAC); }
esp_err_t ads1299_sdatac(ads1299_handle_t* handle) { return ads1299_cmd(handle, ADS_SDATAC); }
esp_err_t ads1299_reset(ads1299_handle_t* handle) { return ads1299_cmd(handle, ADS_RESET); }

esp_err_t ads1299_set_ch_all(ads1299_handle_t* handle, bool en)
{
    uint8_t reg = 0;
    esp_err_t ret = ESP_OK;

    ads1299_sdatac(handle);
    for (int ch = 0; ch < 8; ch++) {
        ret = _ads1299_rreg(handle, ADS_CH1SET + ch, &reg);
        if (ret != ESP_OK) return ret;
        ret = _ads1299_wreg(handle, ADS_CH1SET + ch, en ? (reg & 0x7F) : (reg | 0x80));
        if (ret != ESP_OK) return ret;
    }
    ads1299_rdatac(handle);
    return ret;
}

esp_err_t ads1299_set_ch(ads1299_handle_t* handle, uint8_t ch, bool en)
{
    if (0 > ch || ch > 7) return ESP_ERR_INVALID_ARG;

    uint8_t reg = 0;
    esp_err_t ret = ESP_OK;

    ads1299_sdatac(handle);
    ret = _ads1299_rreg(handle, ADS_CH1SET + ch, &reg);
    if (ret != ESP_OK) return ret;
    ret = _ads1299_wreg(handle, ADS_CH1SET + ch, en ? (reg & 0x7F) : (reg | 0x80));
    if (ret != ESP_OK) return ret;
    ads1299_rdatac(handle);
    return ret;
}

esp_err_t ads1299_get_ch(ads1299_handle_t* handle, uint8_t ch, uint8_t* ret_val)
{
    if (ch < 0 || ch > 7) return ESP_ERR_INVALID_ARG;
        
    esp_err_t ret = ESP_OK;

    ads1299_sdatac(handle);
    ret = _ads1299_rreg(handle, ADS_CH1SET + ch, ret_val);
    ads1299_rdatac(handle);
    return ret;
}
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
